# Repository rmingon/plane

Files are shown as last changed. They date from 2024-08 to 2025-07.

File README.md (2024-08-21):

# PLANE  with 3D models and specific hardware control system 

* SG90 servo
* LD-POWER motor 4300KV
* ESC 8A 
* 2-3s battery

### Thingiverse
[LINK](https://www.thingiverse.com/thing:6716661)

### 3d global view
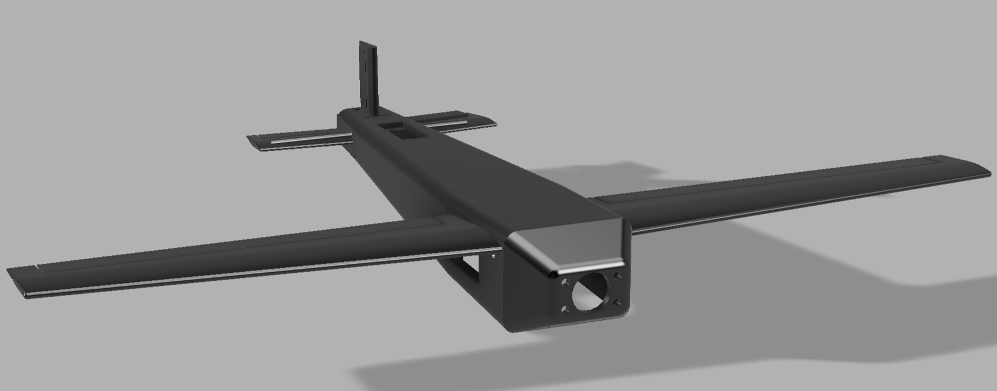
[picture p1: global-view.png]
global view


## Hardware

* ESP32 wifi + bluetooth controller
* LORA 868mhz Long range communication with SMA connector
* 4 channels servos control
* XT30 battery connector
* MPU6050 giro and accel mcu
* BMP280 altimeter
* ESC connector

### 3d view
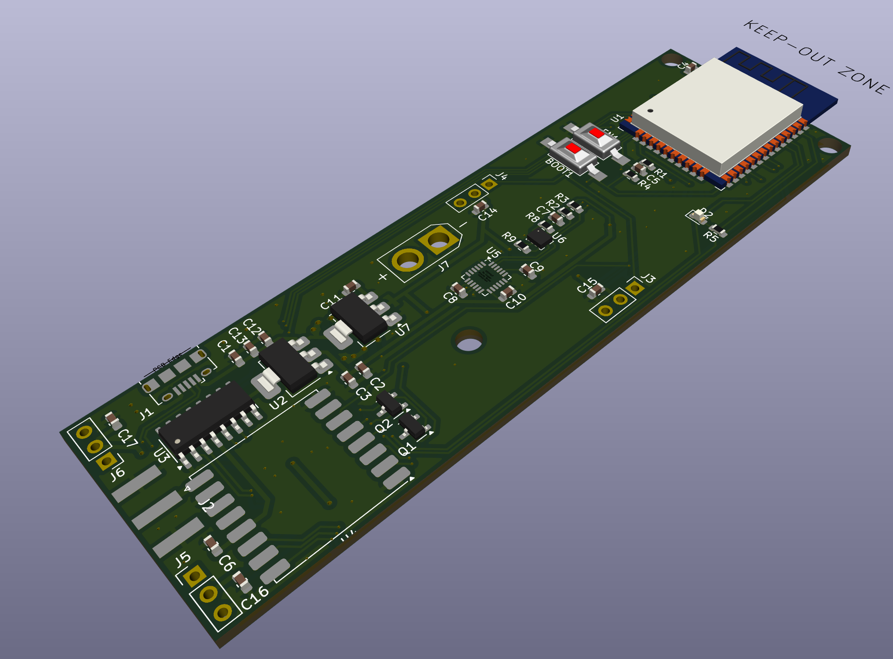
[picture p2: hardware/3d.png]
hardware 3d


### Pcb view
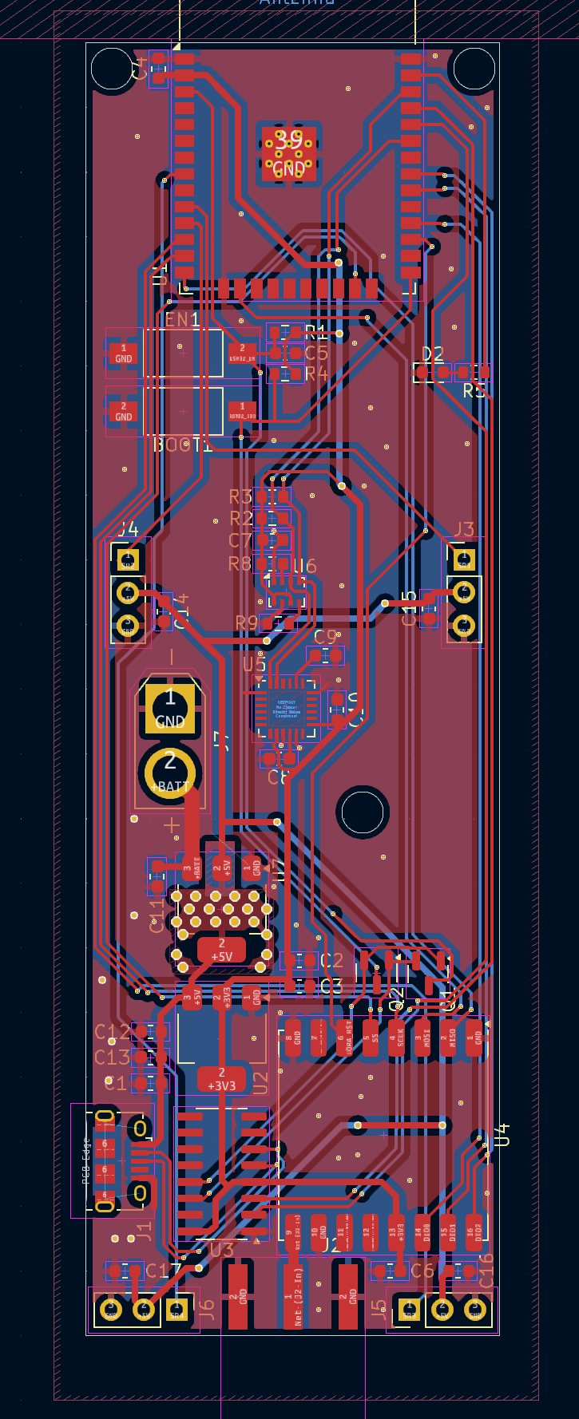
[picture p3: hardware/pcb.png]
hardware pcb
 

### Schematic view
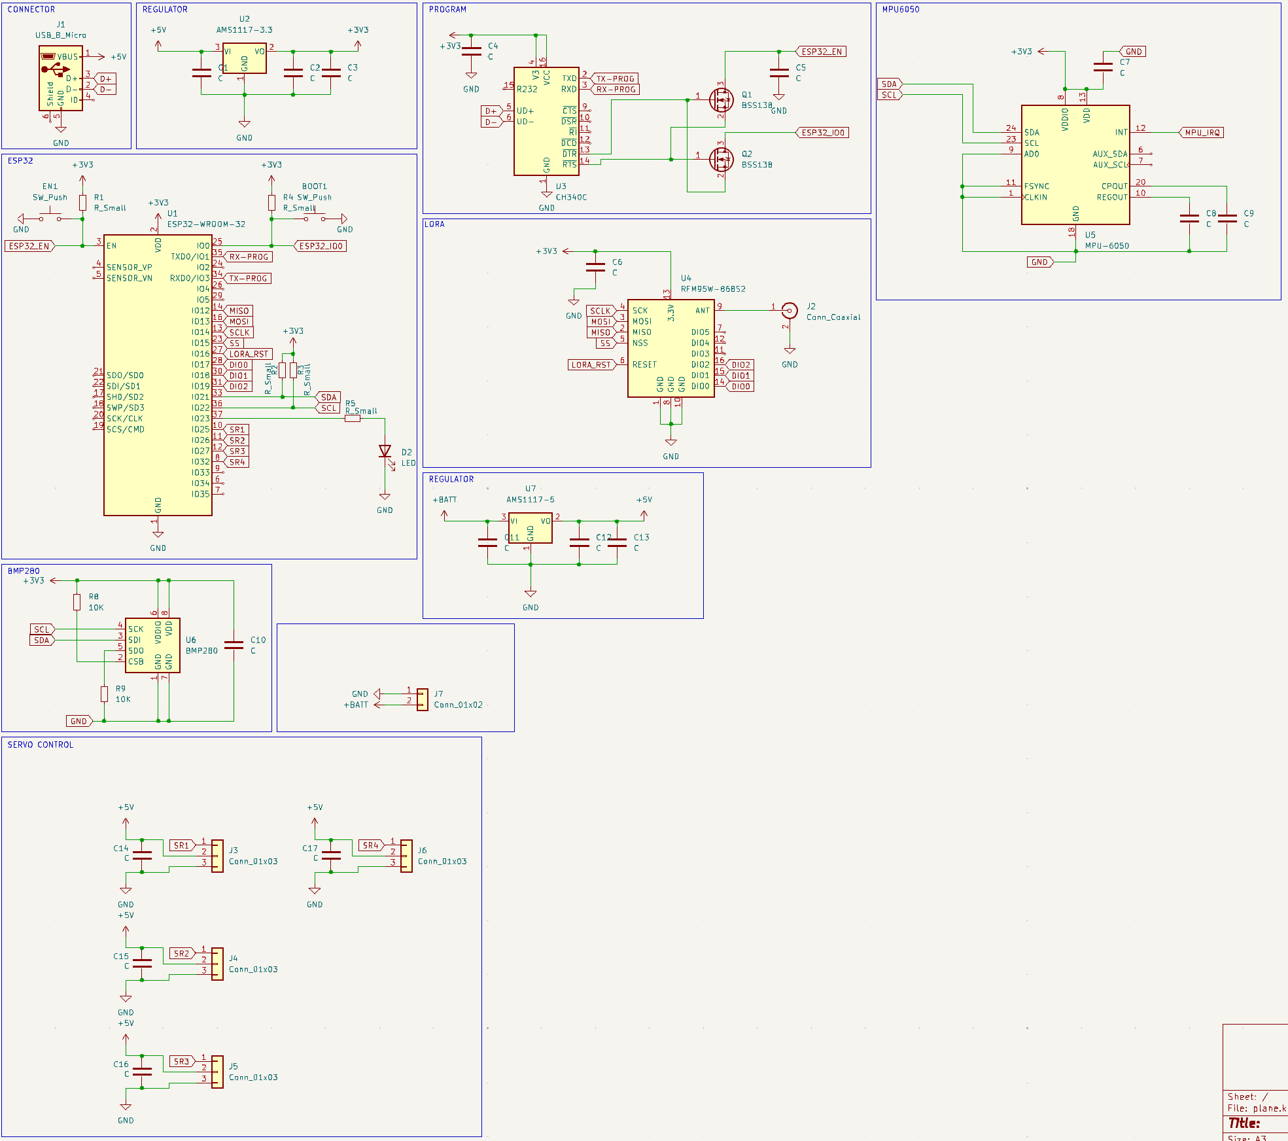
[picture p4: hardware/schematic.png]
hardware schematic


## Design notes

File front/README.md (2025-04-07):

# Front

This project was generated using [Angular CLI](https://github.com/angular/angular-cli) version 19.2.6.

## Development server

To start a local development server, run:

```bash
ng serve
```

Once the server is running, open your browser and navigate to `http://localhost:4200/`. The application will automatically reload whenever you modify any of the source files.

## Code scaffolding

Angular CLI includes powerful code scaffolding tools. To generate a new component, run:

```bash
ng generate component component-name
```

For a complete list of available schematics (such as `components`, `directives`, or `pipes`), run:

```bash
ng generate --help
```

## Building

To build the project run:

```bash
ng build
```

This will compile your project and store the build artifacts in the `dist/` directory. By default, the production build optimizes your application for performance and speed.

## Running unit tests

To execute unit tests with the [Karma](https://karma-runner.github.io) test runner, use the following command:

```bash
ng test
```

## Running end-to-end tests

For end-to-end (e2e) testing, run:

```bash
ng e2e
```

Angular CLI does not come with an end-to-end testing framework by default. You can choose one that suits your needs.

## Additional Resources

For more information on using the Angular CLI, including detailed command references, visit the [Angular CLI Overview and Command Reference](https://angular.dev/tools/cli) page.

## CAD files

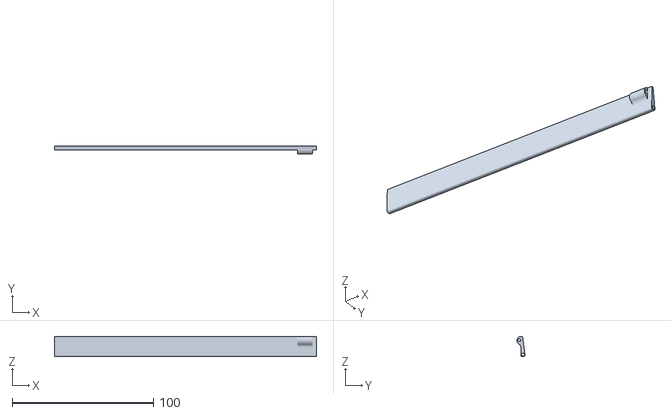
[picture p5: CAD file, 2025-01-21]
3d/flap-left.stl
185.5 x 5.70 x 14.5

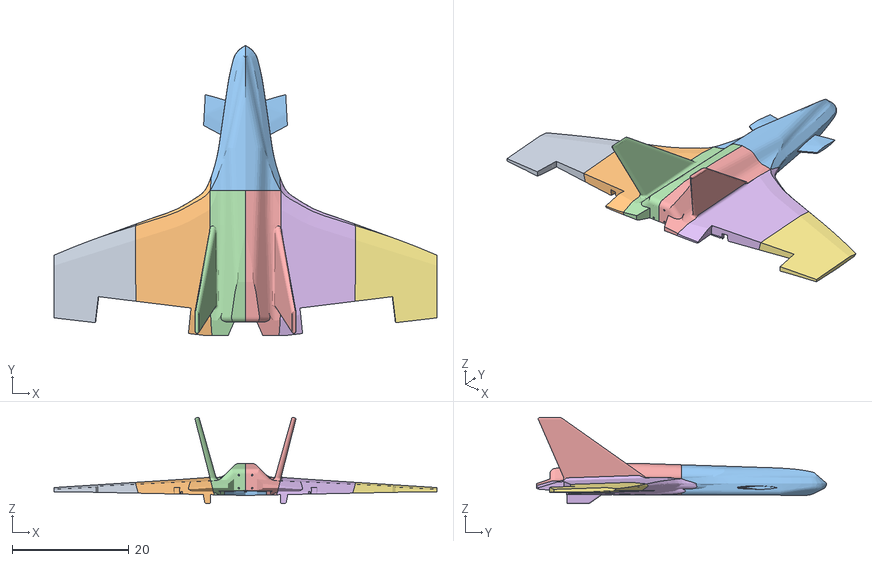
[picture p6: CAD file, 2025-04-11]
front/public/models/plane.obj
65.7 x 49.8 x 14.8
semi (1)
semi (1) (1)
semi (2) (1)
semi (2) (1) (1)
semi (2) (1) (1) (1)
semi (1) (1) (1)
semi (1) (2)

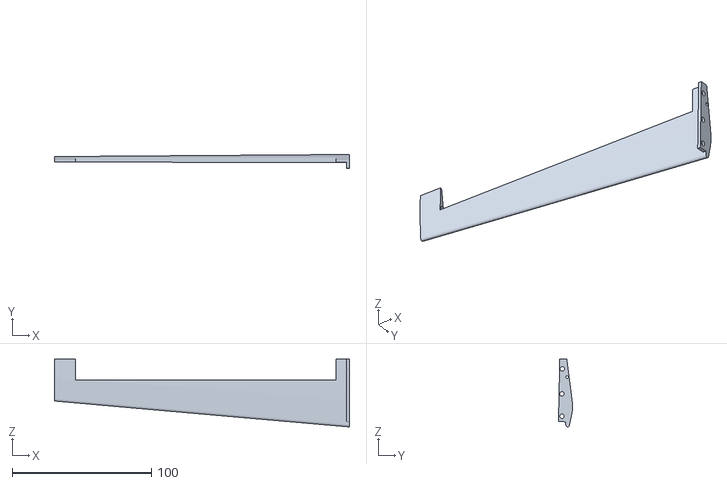
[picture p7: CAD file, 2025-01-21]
3d/wing-left.stl
212.0 x 10.1 x 48.8

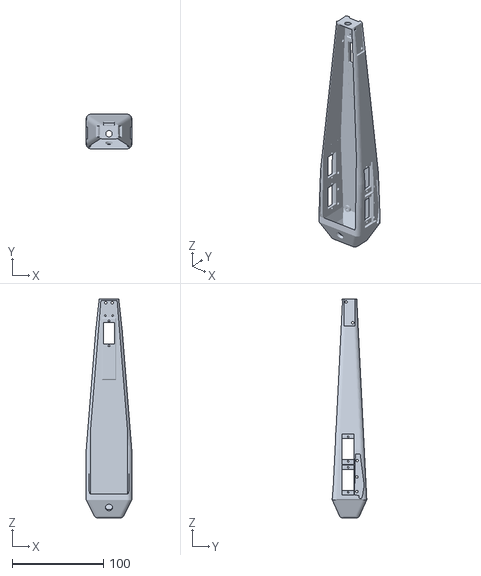
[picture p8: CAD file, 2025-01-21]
3d/plane.stl
50.0 x 38.0 x 240.0

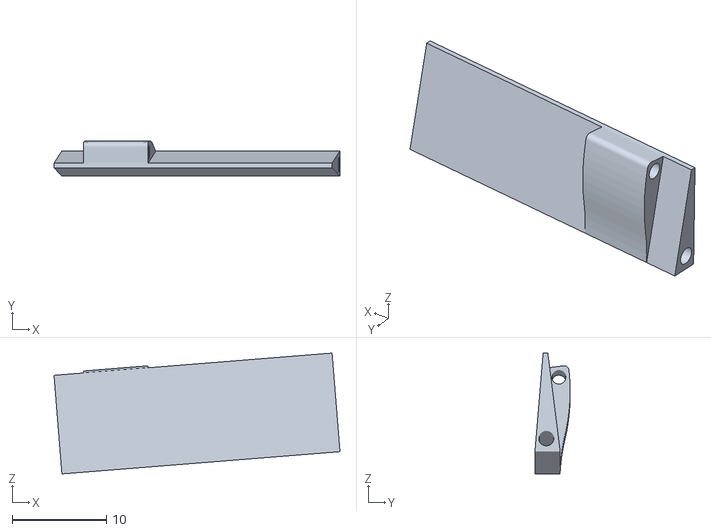
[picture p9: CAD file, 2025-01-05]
3d/tailplane-right-flap.stl
30.4 x 3.74 x 12.8

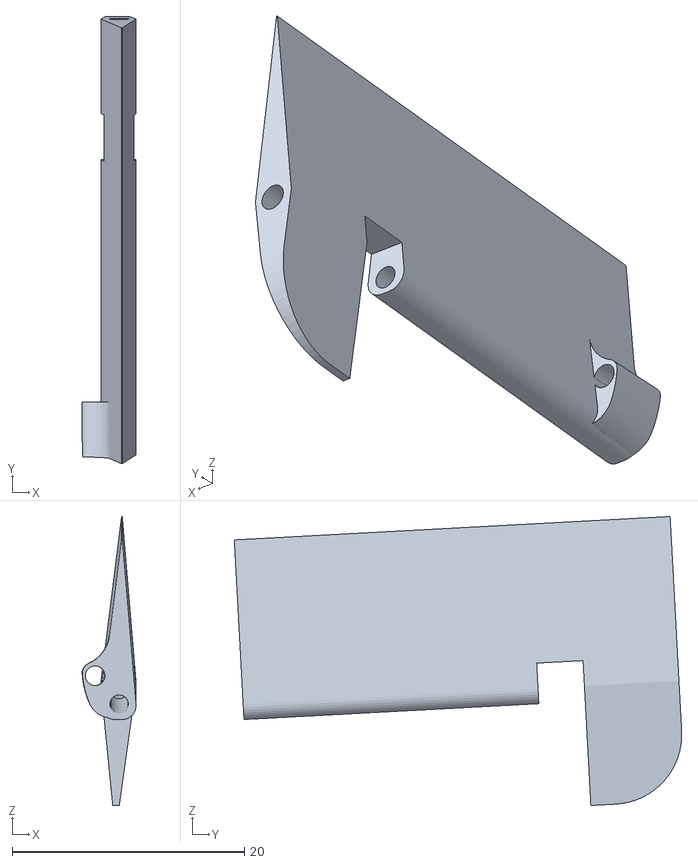
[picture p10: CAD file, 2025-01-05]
3d/fin-flap.stl
4.66 x 38.6 x 24.9

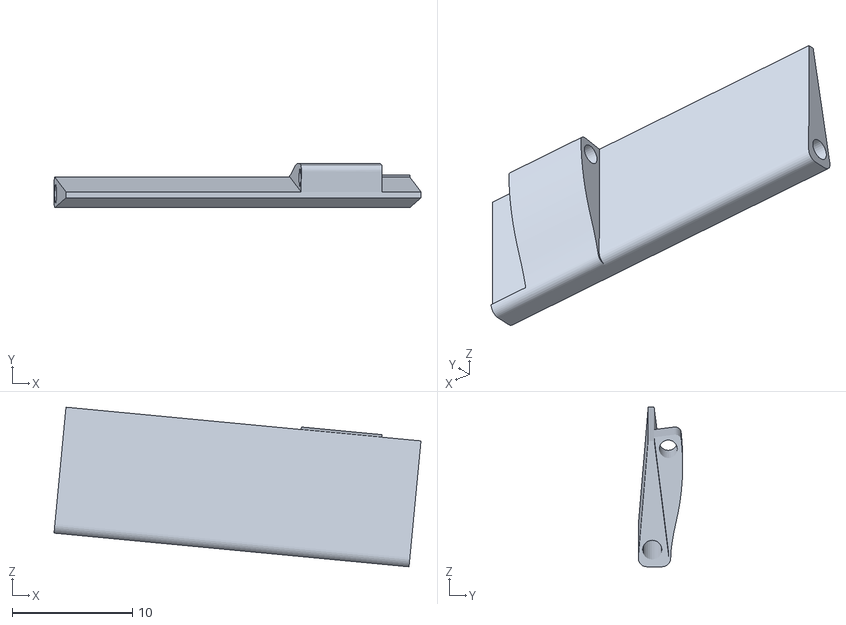
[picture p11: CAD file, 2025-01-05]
3d/tailplane-left-flap.stl
30.5 x 3.67 x 13.3

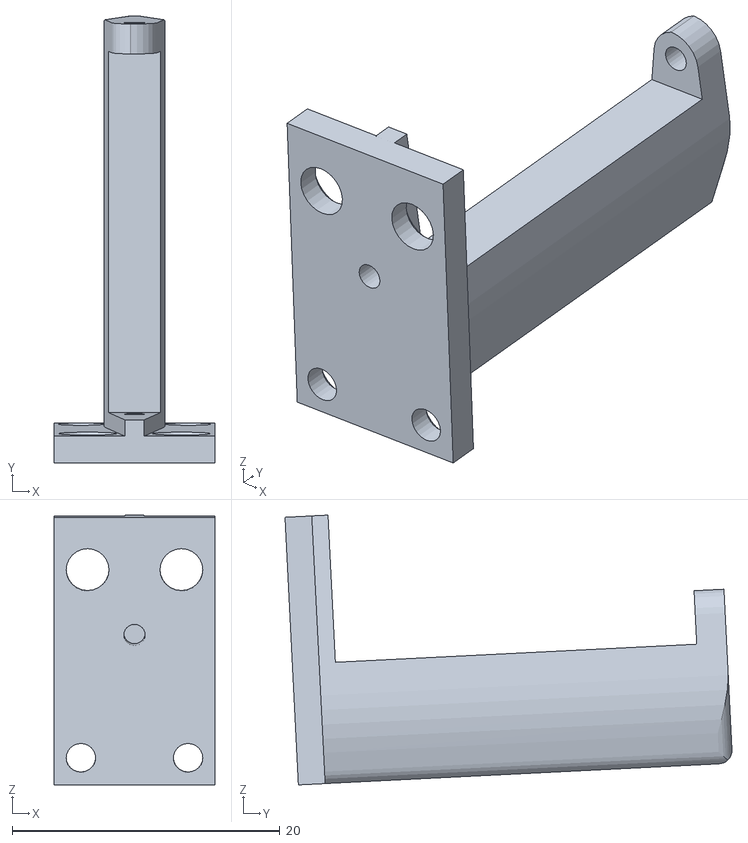
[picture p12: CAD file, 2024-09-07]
3d/fin.stl
12.0 x 33.4 x 20.1

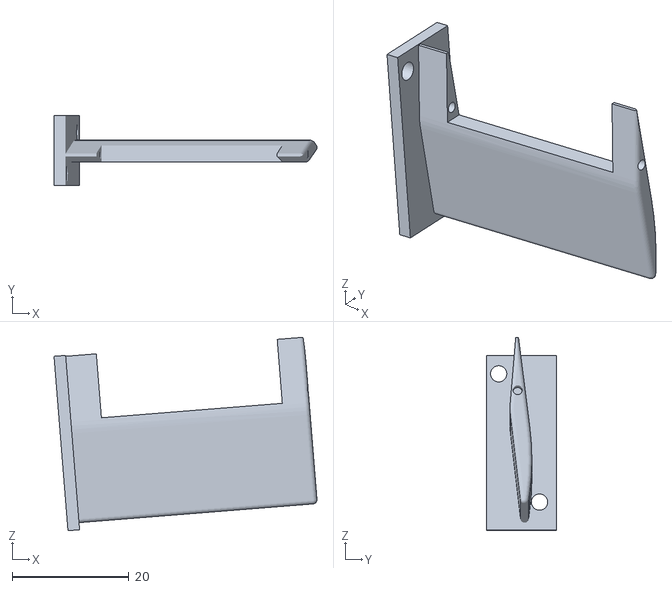
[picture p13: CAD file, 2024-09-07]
3d/tailplane-right.stl
45.1 x 12.0 x 33.2

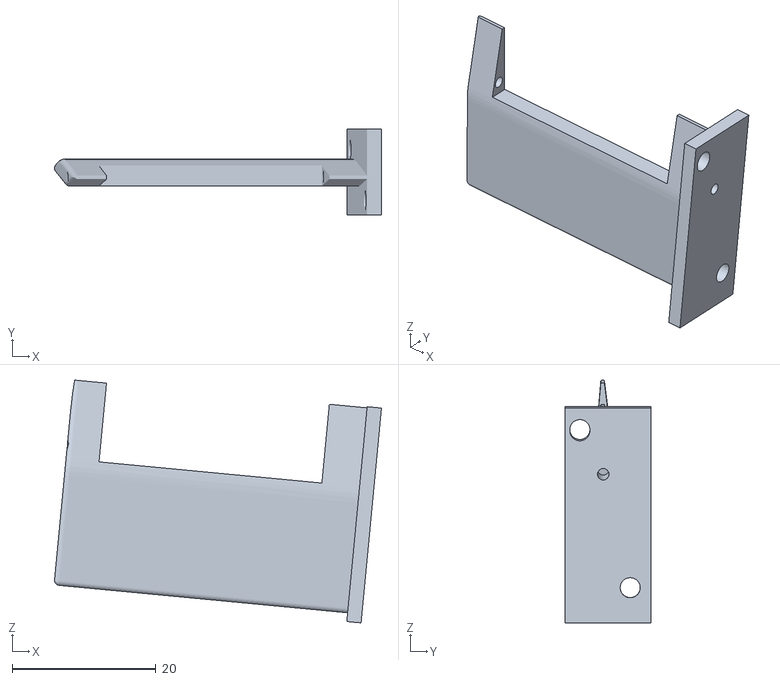
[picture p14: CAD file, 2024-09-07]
3d/tailplane-left.stl
45.5 x 12.0 x 33.8

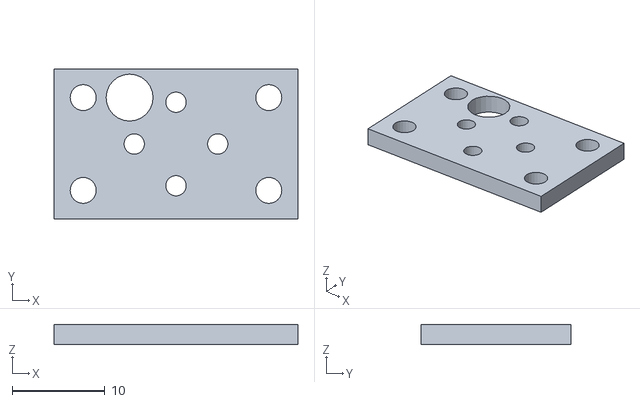
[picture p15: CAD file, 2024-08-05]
3d/motor-support.stl
26.3 x 16.1 x 2.20

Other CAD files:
3d/flap-right.stl
3d/wing-right.stl
3d/fuselage.stl

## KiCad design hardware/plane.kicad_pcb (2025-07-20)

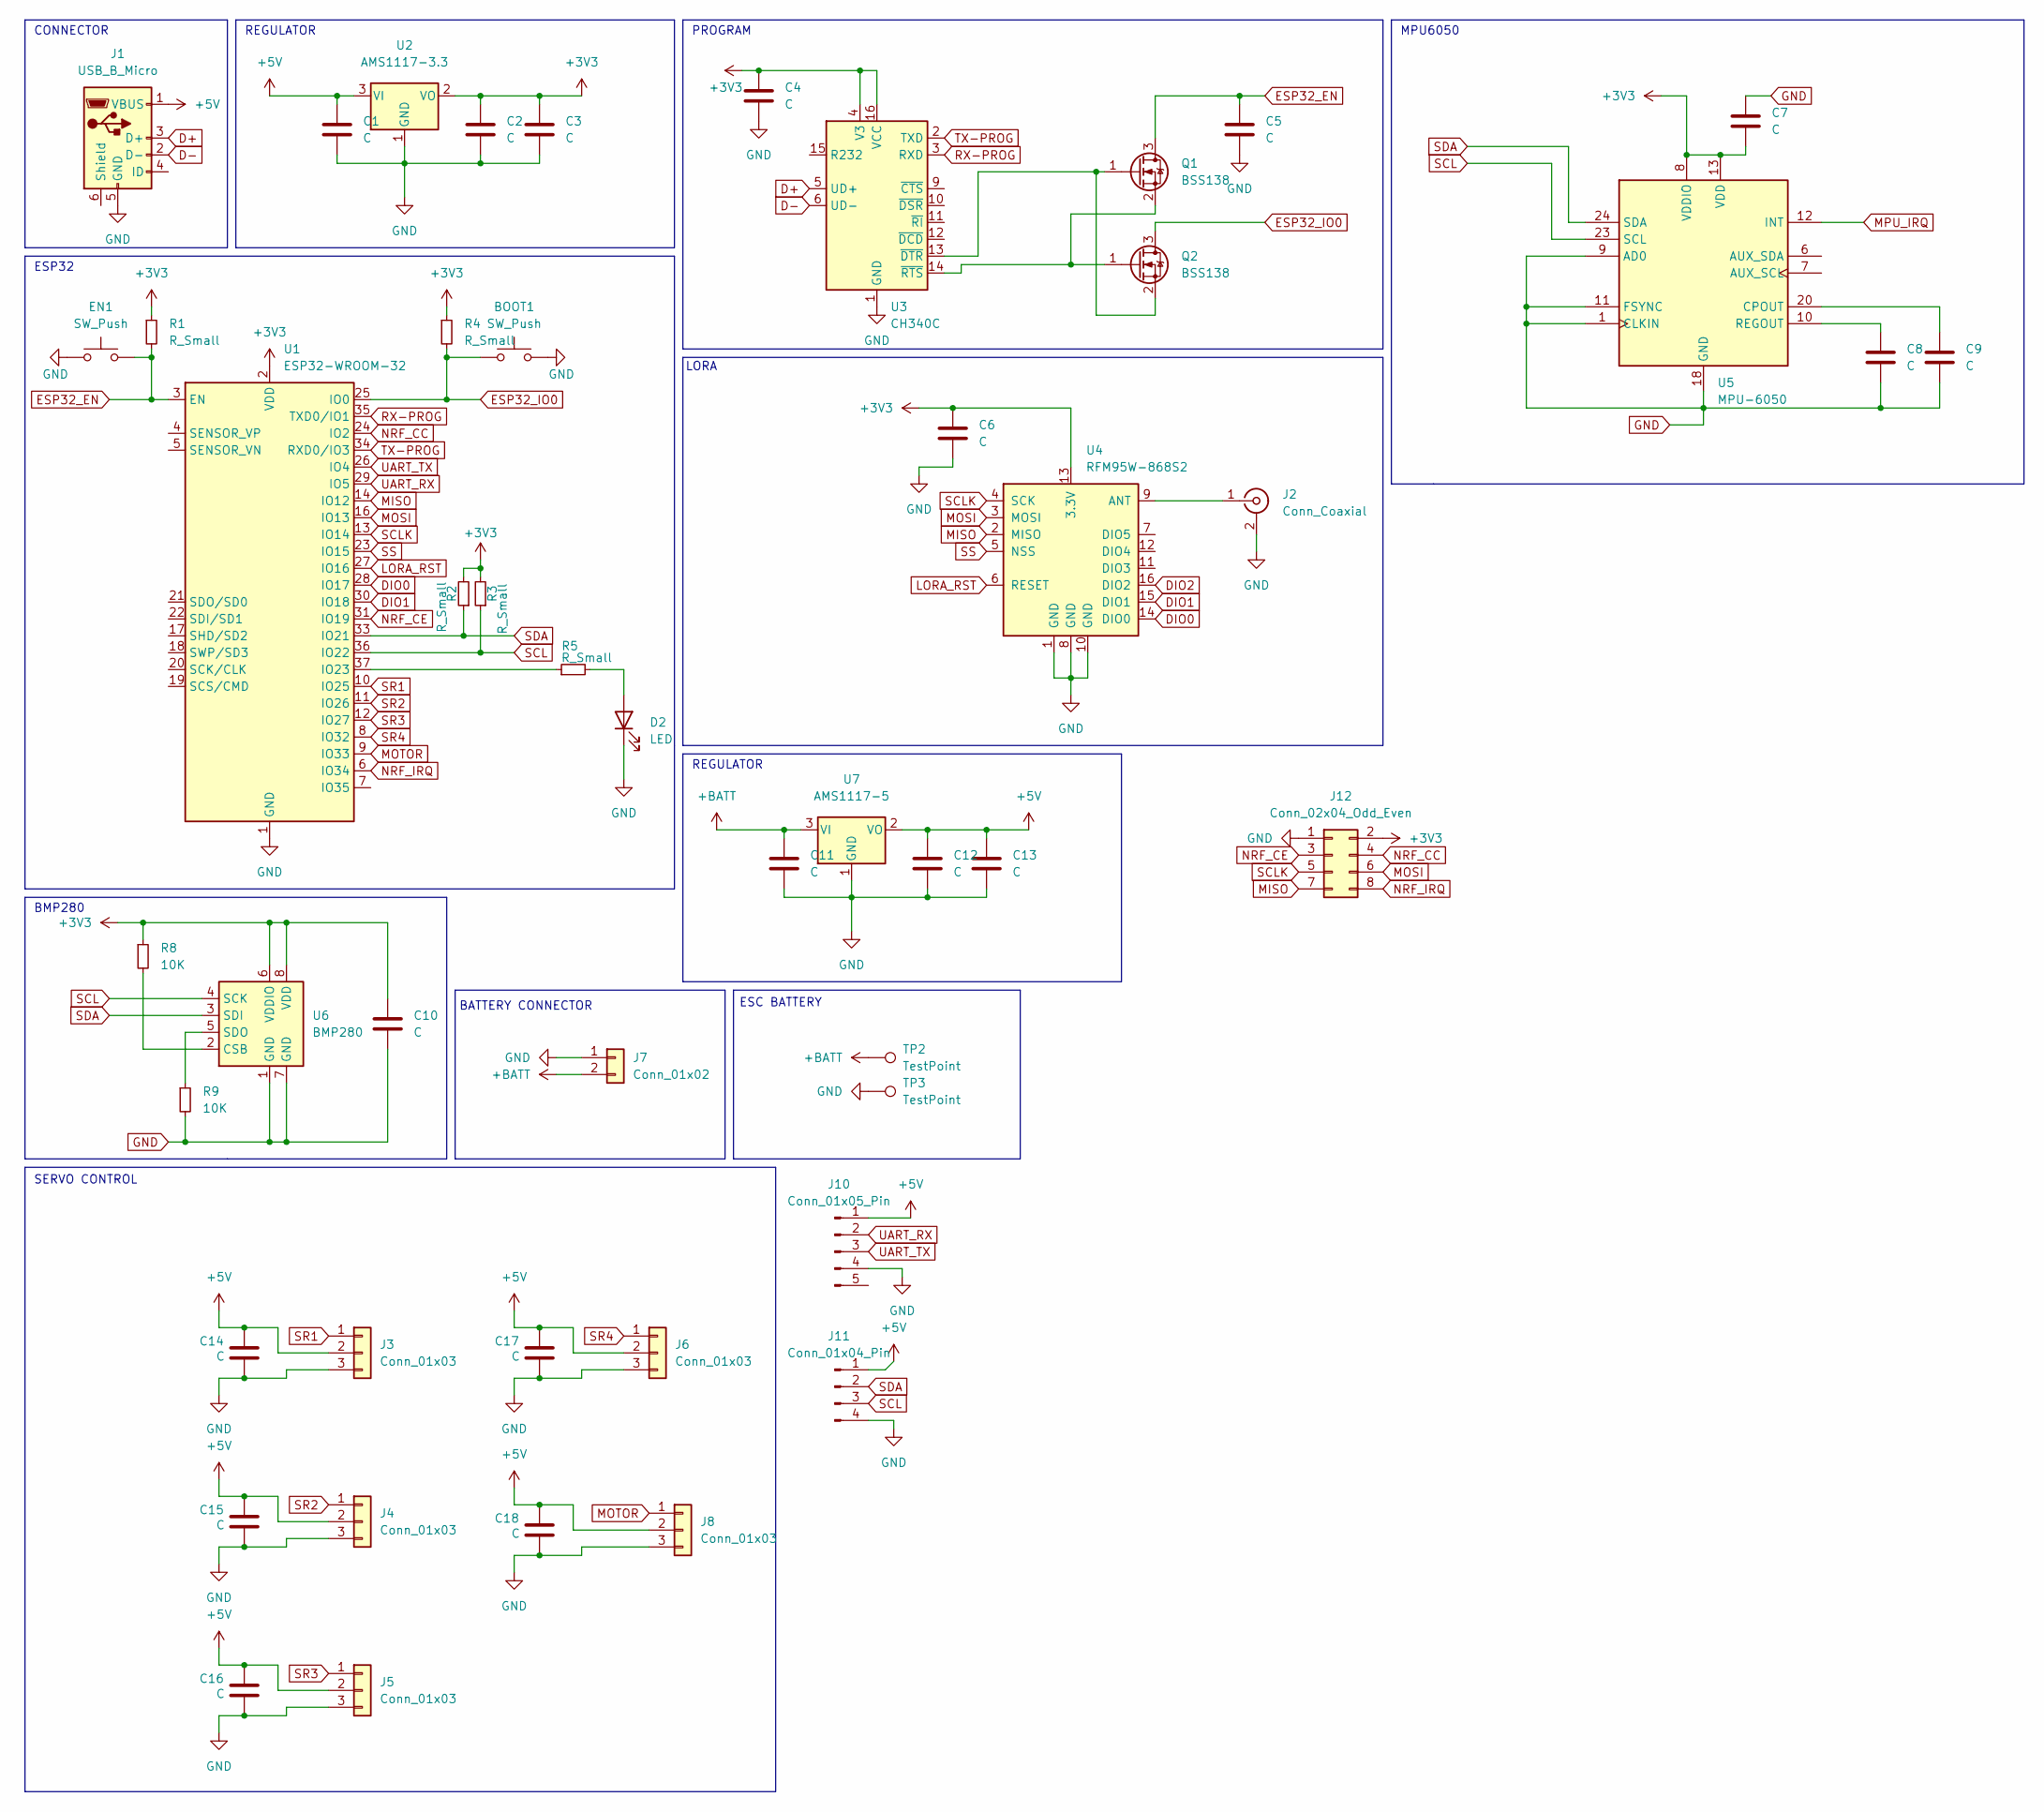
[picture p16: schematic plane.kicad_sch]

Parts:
BOOT1: SW_Push; SW_SPST_FSMSM
C1, C2, C3, C4, C5, C6, C7, C8, C9, C10, C11, C12, C13, C14, C15, C16, C17, C18: C; C_0603_1608Metric
D2: LED; LED_0603_1608Metric
EN1: SW_Push; SW_SPST_FSMSM
J1: USB_B_Micro; USB_Micro-B_Amphenol_10118194_Horizontal
J2: Conn_Coaxial; SMA_Samtec_SMA-J-P-H-ST-EM1_EdgeMount
J3, J4, J5, J6, J8: Conn_01x03; PinHeader_1x03_P2.54mm_Vertical
J7: Conn_01x02; AMASS_XT30U-F_1x02_P5.0mm_Vertical
J10: Conn_01x05_Pin; PinHeader_1x05_P2.54mm_Vertical
J11: Conn_01x04_Pin; PinHeader_1x04_P2.54mm_Vertical
J12: Conn_02x04_Odd_Even; PinHeader_2x04_P2.54mm_Vertical
Q1, Q2: BSS138; SOT-23
R1, R2, R3, R4, R5: R_Small; R_0603_1608Metric
R8, R9: 10K; R_0603_1608Metric
TP2, TP3: TestPoint; TestPoint_Pad_2.5x2.5mm
U1: ESP32-WROOM-32
U2: AMS1117-3.3; SOT-223-3_TabPin2
U3: CH340C; SOIC-16_3.9x9.9mm_P1.27mm
U4: RFM95W-868S2; HOPERF_RFM9XW_SMD
U5: MPU-6050; InvenSense_QFN-24_4x4mm_P0.5mm
U6: BMP280; Bosch_LGA-8_2x2.5mm_P0.65mm_ClockwisePinNumbering
U7: AMS1117-5; SOT-223-3_TabPin2

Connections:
+3V3: C2.1, C3.1, C4.1, C6.1, C7.2, C10.1, J12.2, R1.1, R2.2, R3.2, R4.1, R8.1, U1.2 (VDD), U2.2 (VO), U3.4 (V3), U3.16 (VCC), U4.13 (3.3V), U5.8 (VDDIO), U5.13 (VDD), U6.6 (VDDIO), U6.8 (VDD)
+5V: C1.1, C12.1, C13.1, C14.1, C15.1, C16.1, C17.1, C18.1, J1.1 (VBUS), J3.2, J4.2, J5.2, J6.2, J8.2, J10.1, J11.1, U2.3 (VI), U7.2 (VO)
+BATT: C11.1, J7.2, TP2.1, U7.3 (VI)
D+: J1.3 (D+), U3.5 (UD+)
D-: J1.2 (D-), U3.6 (UD-)
DIO0: U1.28 (IO17), U4.14 (DIO0)
DIO1: U1.30 (IO18), U4.15 (DIO1)
DIO2: U4.16 (DIO2)
ESP32_EN: C5.1, EN1.2, Q1.3 (D), R1.2, U1.3 (EN)
ESP32_IO0: BOOT1.1, Q2.3 (D), R4.2, U1.25 (IO0)
GND: BOOT1.2, C1.2, C2.2, C3.2, C4.2, C5.2, C6.2, C7.1, C8.2, C9.2, C10.2, C11.2, C12.2, C13.2, C14.2, C15.2, C16.2, C17.2, C18.2, D2.1 (K), EN1.1, J1.5 (GND), J2.2 (Ext), J3.3, J4.3, J5.3, J6.3, J7.1, J8.3, J10.4, J11.4, J12.1, R9.2, TP3.1, U1.1 (GND), U1.15 (GND), U1.38 (GND), U1.39 (GND), U2.1 (GND), U3.1 (GND), U4.1 (GND), U4.8 (GND), U4.10 (GND), U5.1 (CLKIN), U5.9 (AD0), U5.11 (FSYNC), U5.18 (GND), U6.1 (GND), U6.7 (GND), U7.1 (GND)
LORA_RST: U1.27 (IO16), U4.6 (RESET)
MISO: J12.7, U1.14 (IO12), U4.2 (MISO)
MOSI: J12.6, U1.16 (IO13), U4.3 (MOSI)
MOTOR: J8.1, U1.9 (IO33)
MPU_IRQ: U5.12 (INT)
NRF_CC: J12.4, U1.24 (IO2)
NRF_CE: J12.3, U1.31 (IO19)
NRF_IRQ: J12.8, U1.6 (IO34)
unnamed: D2.2 (A), R5.2
unnamed: J2.1 (In), U4.9 (ANT)
unnamed: Q1.1 (G), Q2.2 (S), U3.13 (~DTR)
unnamed: Q1.2 (S), Q2.1 (G), U3.14 (~RTS)
unnamed: R5.1, U1.37 (IO23)
unnamed: C9.1, U5.20 (CPOUT)
unnamed: C8.1, U5.10 (REGOUT)
unnamed: R8.2, U6.2 (CSB)
unnamed: R9.1, U6.5 (SDO)
RX-PROG: U1.35 (TXD0/IO1), U3.3 (RXD)
SCL: J11.3, R3.1, U1.36 (IO22), U5.23 (SCL), U6.4 (SCK)
SCLK: J12.5, U1.13 (IO14), U4.4 (SCK)
SDA: J11.2, R2.1, U1.33 (IO21), U5.24 (SDA), U6.3 (SDI)
SR1: J3.1, U1.10 (IO25)
SR2: J4.1, U1.11 (IO26)
SR3: J5.1, U1.12 (IO27)
SR4: J6.1, U1.8 (IO32)
SS: U1.23 (IO15), U4.5 (NSS)
TX-PROG: U1.34 (RXD0/IO3), U3.2 (TXD)
UART_RX: J10.2, U1.29 (IO5)
UART_TX: J10.3, U1.26 (IO4)

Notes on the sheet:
ESP32
REGULATOR
ESC BATTERY
PROGRAM
SERVO CONTROL
BMP280
BATTERY CONNECTOR
MPU6050
CONNECTOR
LORA

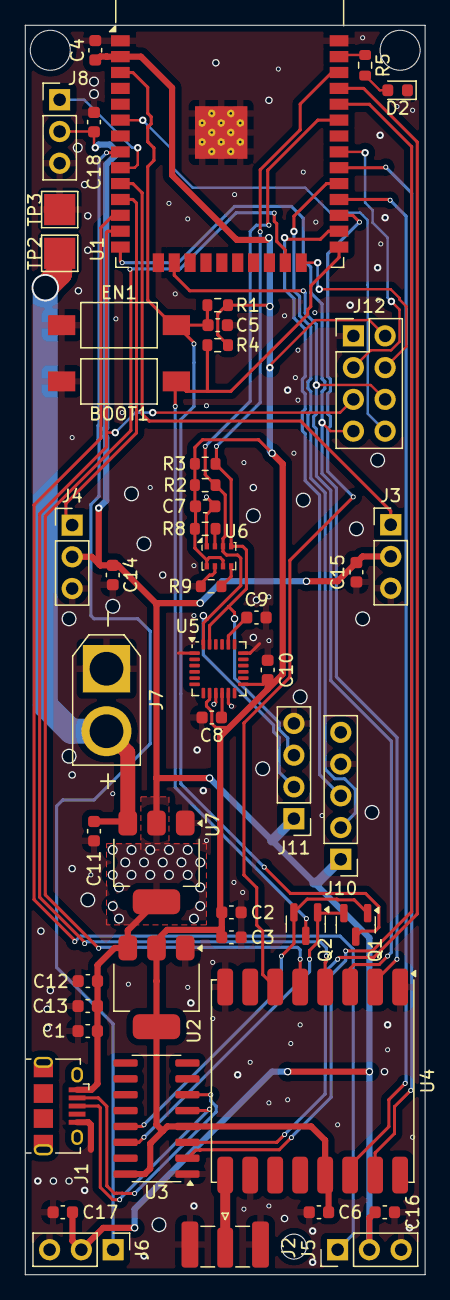
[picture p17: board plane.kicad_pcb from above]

Board: 2 copper layers, 32.0 x 100.0 mm, 50 parts (0 on the bottom side), 38 nets.

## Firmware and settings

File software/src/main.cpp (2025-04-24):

#include <Arduino.h>
#define LED 23

#include "Wire.h"
#include <ArduinoJson.h>
#include <TinyGPSPlus.h>
TinyGPSPlus gps;
HardwareSerial gpsSerial(2);

#include <SPI.h>
#include <LoRa.h>
SPIClass LoRaSPI;

#include <Adafruit_BMP280.h>
Adafruit_BMP280 bmp;

#include <HMC5883L.h>
MagnetometerCalibration calib;

int oESC = 100;

#include <MPU6050_light.h>
MPU6050 mpu(Wire);
long timer = 0;

struct Data {
  float lat;
  float lon;
  float kmph;
  float deg;
  double x;
  double y;
  float alt;
  int16_t magX;
  int16_t magY;
  int16_t magZ;
  int speed;
  byte cmd;
};
Data dataToSend;

struct DataReceive {
  byte command;
  int roll;
  int pitch;
  int throttle;
  double targetAltitude;
};
DataReceive dataReceive;

double currentAltitude= 0;
double currentRoll = 0;
double throttleOutput;
double rollOutput;
double targetRoll = 0;

double currentPitch = 0;
double targetPitch = 0;
double outputPitch = 0;

#include <PID_v1.h>
double Kp = 2.0, Ki = 0.5, Kd = 1.0;
double rollKp = 1.5, rollKi = 0.3, rollKd = 0.8;
double pitchKp = 1.5, pitchKi = 0.3, pitchKd = 0.8;
PID altitudePID(&currentAltitude, &throttleOutput, &dataReceive.targetAltitude, Kp, Ki, Kd, DIRECT);
PID rollPID(&currentRoll, &rollOutput, &targetRoll, rollKp, rollKi, rollKd, DIRECT);
PID pitchPID(&currentPitch, &outputPitch, &targetPitch, pitchKp, pitchKi, pitchKd, DIRECT);

struct HmcData {
  int16_t x;
  int16_t y;
  int16_t z;
};

#include <ESP32Servo.h>
Servo left;
Servo right;
Servo esc;

void loraSend(byte*, size_t);
void displayInfo();
void autoPilot();
void calibEsc();
void testEsc();
void roll(double);
void yaw(int);

void onReceive(int packetSize) {
  if (packetSize == sizeof(dataReceive)) {
    digitalWrite(LED, !digitalRead(LED));

    for (int i = 0; i < sizeof(dataReceive); i++) {
      *((uint8_t*)&dataReceive + i) = LoRa.read();
    }
    const int cPosition = 0;
    const int zPosition = 1;

    bool cIsPressed = (dataReceive.command & (1 << cPosition)) != 0;
    bool zIsPressed = (dataReceive.command & (1 << zPosition)) != 0;

    // Serial.println("pitch: " + String(dataReceive.pitch));
    // Serial.println("roll: " + String(dataReceive.roll));
    targetRoll = dataReceive.roll;
  }
}

volatile bool sendEnd = false;

void calibEsc() {
    Serial.println("Starting ESC calibration...");
    
    // Step 1: Send max throttle
    esc.writeMicroseconds(2000);
    Serial.println("Sending MAX throttle...");
    delay(5000);  // Wait for ESC beep sequence

    // Step 2: Send min throttle
    esc.writeMicroseconds(1000);
    Serial.println("Sending MIN throttle...");
    delay(5000);  // Wait for ESC confirmation

    Serial.println("ESC Calibration complete!");
}

void testEsc () {
    esc.write(30);  // Slow speed
    delay(3000);
    
    esc.write(60);  // Medium speed
    delay(3000);
    
    esc.write(80);  // High speed
    delay(3000);
    
    esc.write(100);  // High speed
    delay(3000);
    
    esc.write(60);  // High speed
    delay(3000);
    
    esc.write(20);  // High speed
    delay(3000);
    
    esc.write(0);  // Stop
    delay(3000);
}

int leftServoOffset = 0;
int rightServoOffset = 0;

void setup() {
  setCpuFrequencyMhz(240);
  pinMode(LED, OUTPUT);
  Wire.begin();
  Serial.begin(115200);
  gpsSerial.begin(9600, SERIAL_8N1, 4, 5);

  ESP32PWM::allocateTimer(0);
	ESP32PWM::allocateTimer(1);
	ESP32PWM::allocateTimer(2);
	ESP32PWM::allocateTimer(3);

  esc.setPeriodHertz(50);
  esc.attach(33, 1000, 2000);

  calibEsc();

  left.setPeriodHertz(50);
  left.attach(26, 1000, 2000);
  right.setPeriodHertz(50);
  right.attach(25, 1000, 2000);

  left.write(40);
  
  right.write(80);
  
  LoRaSPI.begin(14, 12, 13);
  LoRa.setSPIFrequency(12000000);
  LoRa.setSPI(LoRaSPI);
  LoRa.setPins(15, 16, 17);
  if (!LoRa.begin(868E6)) {
      Serial.println("LoRa init failed. Check your connections.");
      while (true);
  }
  LoRa.setSignalBandwidth(250E3);
  LoRa.setCodingRate4(8);
  LoRa.setSpreadingFactor(7);
  LoRa.setTxPower(20);
  LoRa.setSyncWord(0xF3);
  LoRa.enableCrc();

  if (!bmp.begin()) {
      Serial.println(F("Could not find a valid BMP280 sensor, check wiring or "
                      "try a different address!"));
      while (true);
  }
  bmp.setSampling(Adafruit_BMP280::MODE_FORCED,
  Adafruit_BMP280::SAMPLING_X2,  
  Adafruit_BMP280::SAMPLING_X16,   
  Adafruit_BMP280::FILTER_X16,     
  Adafruit_BMP280::STANDBY_MS_500); 

  byte status = mpu.begin();
  while(status!=0){ } // stop everything if could not connect to MPU6050
  mpu.calcOffsets(true,true); // gyro and accelero

  currentAltitude = bmp.readAltitude(1016);
  dataReceive.targetAltitude = currentAltitude;

  altitudePID.SetMode(AUTOMATIC);
  rollPID.SetMode(AUTOMATIC);
  rollPID.SetOutputLimits(-50, 50);
  pitchPID.SetMode(AUTOMATIC);
  pitchPID.SetOutputLimits(-50, 50);

  initHMC5883L();
  calib = calibrateHMC5883L();
  Serial.print("GO");
}

void roll(double roll) {
  left.write(40 - (roll));
  right.write(80 - (roll));
}

void yaw(unsigned int yaw) {
  // backRight.write(100 - yaw);
}

void loop() {
  onReceive(LoRa.parsePacket());

  altitudePID.Compute();
  rollPID.Compute();
  pitchPID.Compute();

  roll(rollOutput);
  esc.write(throttleOutput);

  while (gpsSerial.available() > 0)
    if (gps.encode(gpsSerial.read())) {
      dataToSend.lat = gps.location.isValid() ? gps.location.lat() : 0.0;
      dataToSend.lon = gps.location.isValid() ? gps.location.lng() : 0.0;
      dataToSend.kmph = gps.speed.isValid() ? gps.speed.kmph() : 0.0;
      dataToSend.deg = gps.course.isValid() ? gps.course.deg() : 0.0;
    }

  mpu.update();
  dataToSend.x = mpu.getAngleX();
  dataToSend.y = mpu.getAngleY();
  currentRoll = mpu.getAngleY();

  if (bmp.takeForcedMeasurement()) {
    dataToSend.alt = bmp.readAltitude(1016);
    currentAltitude = dataToSend.alt;
  }
    
  readCalibratedHMC5883L(calib, dataToSend.magX, dataToSend.magY, dataToSend.magZ);
  if(millis() - timer > 500) {
    dataToSend.speed = oESC;

    loraSend((uint8_t*)&dataToSend, sizeof(dataToSend));
    timer = millis();
  }
}

void autoPilot() {
  mpu.update();
  roll(int(trunc(mpu.getAccAngleY()*2)));
}

void loraSend(byte* data, size_t length) {
  LoRa.beginPacket();
  LoRa.write(data, length);
  LoRa.endPacket();
  LoRa.receive();
}

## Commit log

2024-08-01 add readme +move views
    [fin.stl, flap-left.stl, flap-right.stl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]
2024-08-01 update motor kv
2024-08-02 add hardware
    [plane.kicad_pcb, plane.kicad_sch]
2024-08-02 add esp32 + program circuit
    [plane.kicad_sch]
2024-08-02 update fuselage
    [fuselage.stl]
2024-08-02 add lora
    [plane.kicad_sch]
2024-08-02 add mpu + bmp
    [plane.kicad_sch]
2024-08-02 add footprints
    [plane.kicad_sch]
2024-08-02 add servos + pcb size
    [plane.kicad_sch]
2024-08-02 add servo pin + wiring pcb
    [plane.kicad_pcb, plane.kicad_sch]
2024-08-02 wiring servo
    [plane.kicad_pcb, plane.kicad_sch]
2024-08-02 i2c wiring
    [plane.kicad_pcb, plane.kicad_sch]
2024-08-03 wiring + battery connector
    [plane.kicad_pcb, plane.kicad_sch]
2024-08-03 pcb battery connector
    [plane.kicad_pcb, plane.kicad_sch]
2024-08-03 add sma connector info
2024-08-03 add esc connector
    [plane.kicad_pcb, plane.kicad_sch]
2024-08-03 esc connector
2024-08-05 update 3d
    [fin-flap.stl, fin.stl, flap-left.stl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]
2024-08-05 update setting
    [plane.kicad_pcb]
2024-08-24 upgrade esc connector & sma
    [plane.kicad_pcb, plane.kicad_sch]
2025-01-05 update flaps
    [fin-flap.stl, tailplane-left-flap.stl, tailplane-right-flap.stl]
2025-01-17 add esc calibrate + pid setting
2025-01-17 add roll + yaw method
2025-01-21 plane with extended wings
    [flap-left.stl, flap-right.stl, plane.stl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]
2025-01-22 add servo connector
    [plane.kicad_pcb, plane.kicad_sch]
2025-01-23 add esc control via nunchuk
2025-02-24 add i2c and uart connectors
    [plane.kicad_pcb, plane.kicad_sch]
2025-04-11 add front plane instruments
    [plane.obj]
2025-04-24 update PID and data lora
    [plane.kicad_pcb, plane.kicad_sch]
2025-07-20 add nrf24l01 connector
    [plane.kicad_pcb, plane.kicad_sch]
